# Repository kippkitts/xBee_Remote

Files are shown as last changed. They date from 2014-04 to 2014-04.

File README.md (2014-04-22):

xBee_Remote
===========

The XBee Remote is a fully programmable remote control that can be used to operate robots or other systems that are equipped with an XBee transceiver.  It features two thumb joysticks, five pushbutton switches, and an LCD display, the functions of which can be programmed into the onboard Atmega32u4 microcontroller.  This repository contains the Eagle files for the remote.

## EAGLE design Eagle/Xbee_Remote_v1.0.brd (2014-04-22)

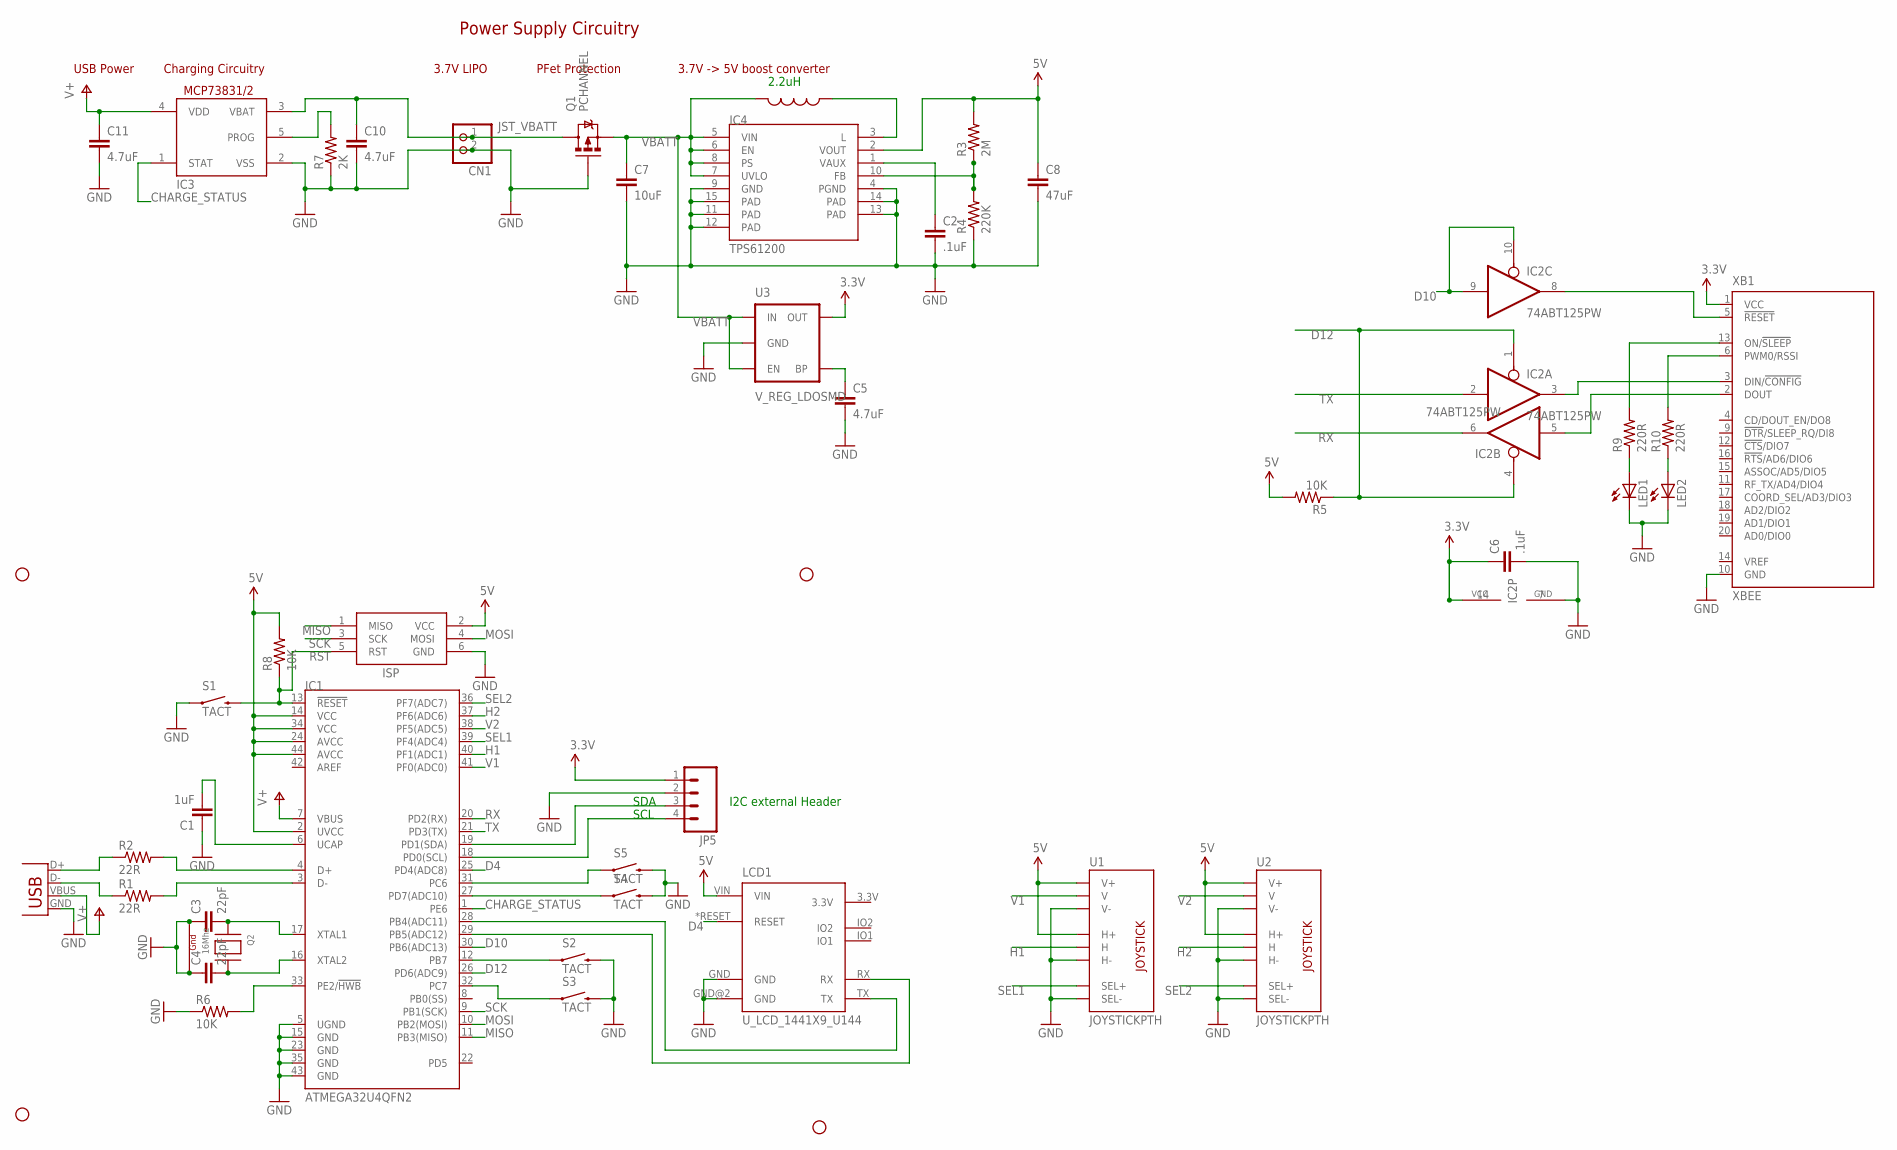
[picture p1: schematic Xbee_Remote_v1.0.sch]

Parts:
C1: 1uF; 0805
C2, C6: .1uF; 0805
C3, C4: 22pF; 0805
C5, C10, C11: 4.7uF; 0805
C7: 10uF; 0805
C8: 47uF; 1206
CN1: JST_2PIN-SMT-RA; JST-PH-2-SMT-RA
IC1: ATMEGA32U4QFN2; QFN-44-NOPAD
IC2: 74ABT125PW; TSSOP14
IC3: MCP73831/OT; SOT23-5L
IC4: TPS61200; QFN-10_PAD
ISP: AVRISP-6; AVRISP
JP1, JP2, JP3, JP4: STAND-OFF
JP5: M04PTH; 1X04
L1: 2.2uH; COILCRAFT_EPL2014
LCD1: U_LCD_1441X9_U144; U_LCD_144
LED1, LED2: LEDCHIPLED_0805; CHIPLED_0805
Q1: PCHANNEL; SOT23-3
Q2: 16Mhz; NX3225
R1, R2: 22R; 0805
R3: 2M; 0805
R4: 220K; 0805
R5, R6, R8: 10K; 0805
R7: 2K; 0805
R9, R10: 220R; 0805
S1, S2, S3, S4, S5: TACT; TACTILE_SWITCH_SMD
U1, U2: JOYSTICKPTH; JOYSTICK
U3: V_REG_LDOSMD; SOT23-5
X1: USB-MICROB
XB1: XBEE

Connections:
3.3V: C6.1, IC2.14 (VCC), JP5.1, U3.5 (OUT), XB1.1 (VCC)
5V: C8.1, IC1.2 (UVCC), IC1.14 (VCC), IC1.24 (AVCC), IC1.34 (VCC), IC1.44 (AVCC), IC4.2 (VOUT), ISP.2 (VCC), LCD1.VIN, R3.2, R5.2, R8.2, U1.H1 (H+), U1.V1 (V+), U2.H1 (H+), U2.V1 (V+)
CHARGE_STATUS: IC1.1 (PE6), IC3.1 (STAT)
D2: IC1.19 (PD1(SDA)), JP5.3
D3: IC1.18 (PD0(SCL)), JP5.4
D4: IC1.25 (PD4(ADC8)), LCD1.*RESET (RESET)
D5: IC1.31 (PC6), S5.1
D6: IC1.27 (PD7(ADC10)), S4.1
D10: IC1.30 (PB6(ADC13)), IC2.9 (I), IC2.10 (OE)
D11: IC1.12 (PB7), S2.1
D12: IC1.26 (PD6(ADC9)), IC2.1 (OE), IC2.4 (OE), R5.1
D13: IC1.32 (PC7), S3.1
GND: C1.1, C2.2, C3.1, C4.1, C5.2, C6.2, C7.2, C8.2, C10.2, C11.2, CN1.2 (1), IC1.5 (UGND), IC1.15 (GND), IC1.23 (GND), IC1.35 (GND), IC1.43 (GND), IC2.7 (GND), IC3.2 (VSS), IC4.4 (PGND), IC4.9 (GND), IC4.11 (PAD), IC4.12 (PAD), IC4.13 (PAD), IC4.14 (PAD), IC4.15 (PAD), ISP.6 (GND), JP5.2, LCD1.GND, LCD1.GND@2 (GND), LED1.C, LED2.C, Q1.1 (G), Q2.2 (G1), Q2.4 (G2), R4.1, R6.1, R7.1, S1.1, S2.3 (2), S3.3 (2), S4.3 (2), S5.3 (2), U1.B2A (SEL-), U1.H3 (H-), U1.V3 (V-), U2.B2A (SEL-), U2.H3 (H-), U2.V3 (V-), U3.2 (GND), X1.GND, XB1.10 (GND)
H1: IC1.40 (PF1(ADC1)), U1.H2 (H)
H2: IC1.37 (PF6(ADC6)), U2.H2 (H)
JST_VBATT: C10.1, CN1.1 (2), IC3.3 (VBAT), Q1.3 (D)
LCD_RX: IC1.29 (PB5(ADC12)), LCD1.RX
LCD_TX: IC1.28 (PB4(ADC11)), LCD1.TX
MISO: IC1.11 (PB3(MISO)), ISP.1 (MISO)
MOSI: IC1.10 (PB2(MOSI)), ISP.4 (MOSI)
unnamed: R2.1, X1.D+
unnamed: R1.1, X1.D-
unnamed: IC1.4 (D+), R2.2
unnamed: IC1.3 (D-), R1.2
unnamed: C1.2, IC1.6 (UCAP)
unnamed: IC3.5 (PROG), R7.2
unnamed: IC4.3 (L), L1.P$1 (1)
unnamed: C5.1, U3.4 (BP)
unnamed: IC4.10 (FB), R3.1, R4.2
unnamed: C2.1, IC4.1 (VAUX)
unnamed: C3.2, IC1.17 (XTAL1), Q2.1 (X1)
unnamed: C4.2, IC1.16 (XTAL2), Q2.3 (X2)
unnamed: IC2.8 (O), XB1.5 (!RESET)
unnamed: IC1.33 (PE2/!HWB), R6.2
unnamed: LED1.A, R9.1
unnamed: LED2.A, R10.1
ON: R9.2, XB1.13 (ON/!SLEEP)
RSSI: R10.2, XB1.6 (PWM0/RSSI)
RST: IC1.13 (!RESET), ISP.5 (RST), R8.1, S1.3 (2)
RX: IC1.20 (PD2(RX)), IC2.6 (O)
SCK: IC1.9 (PB1(SCK)), ISP.3 (SCK)
SEL1: IC1.39 (PF4(ADC4)), U1.B1A (SEL+)
SEL2: IC1.36 (PF7(ADC7)), U2.B1A (SEL+)
TX: IC1.21 (PD3(TX)), IC2.2 (I)
V1: IC1.41 (PF0(ADC0)), U1.V2 (V)
V2: IC1.38 (PF5(ADC5)), U2.V2 (V)
V+: C11.1, IC1.7 (VBUS), IC3.4 (VDD), X1.VBUS
VBATT: C7.1, IC4.5 (VIN), IC4.6 (EN), IC4.7 (UVLO), IC4.8 (PS), L1.P$2 (2), Q1.2 (S), U3.1 (IN), U3.3 (EN)
XBEE_RX: IC2.3 (O), XB1.3 (DIN/!CONFIG)
XBEE_TX: IC2.5 (I), XB1.2 (DOUT)

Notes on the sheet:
3.7V LIPO
PFet Protection
3.7V -> 5V boost converter
Power Supply Circuitry
USB Power
Charging Circuitry
2.2uH
I2C external Header
SDA
SCL

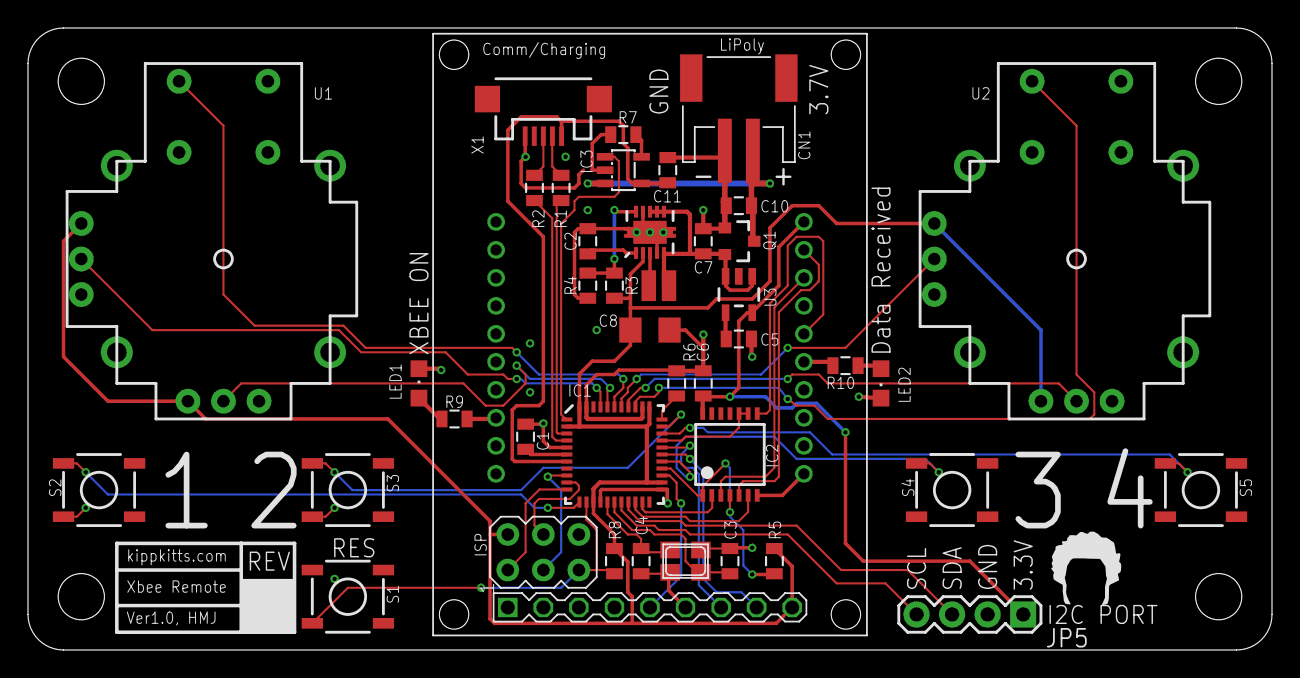
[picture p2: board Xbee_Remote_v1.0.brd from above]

Board: 2 copper layers, 88.9 x 44.5 mm, 48 parts (1 on the bottom side), 50 nets.

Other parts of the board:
U$9: TOP_DOCU_5MM

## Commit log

2014-03-26 Create Repository
    [xbee_remote.brd, xbee_remote.sch]
2014-04-22 Replace Eagle Files
    [Xbee_Remote_v1.0.brd, Xbee_Remote_v1.0.sch, xbee_remote.brd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]

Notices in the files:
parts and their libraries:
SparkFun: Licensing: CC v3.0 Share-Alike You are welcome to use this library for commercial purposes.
